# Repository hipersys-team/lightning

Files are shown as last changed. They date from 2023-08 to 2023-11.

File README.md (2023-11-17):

# Lightning: A Reconfigurable Photonic-Electronic SmartNIC for Fast and Energy-Efficient Inference




<p align="center">
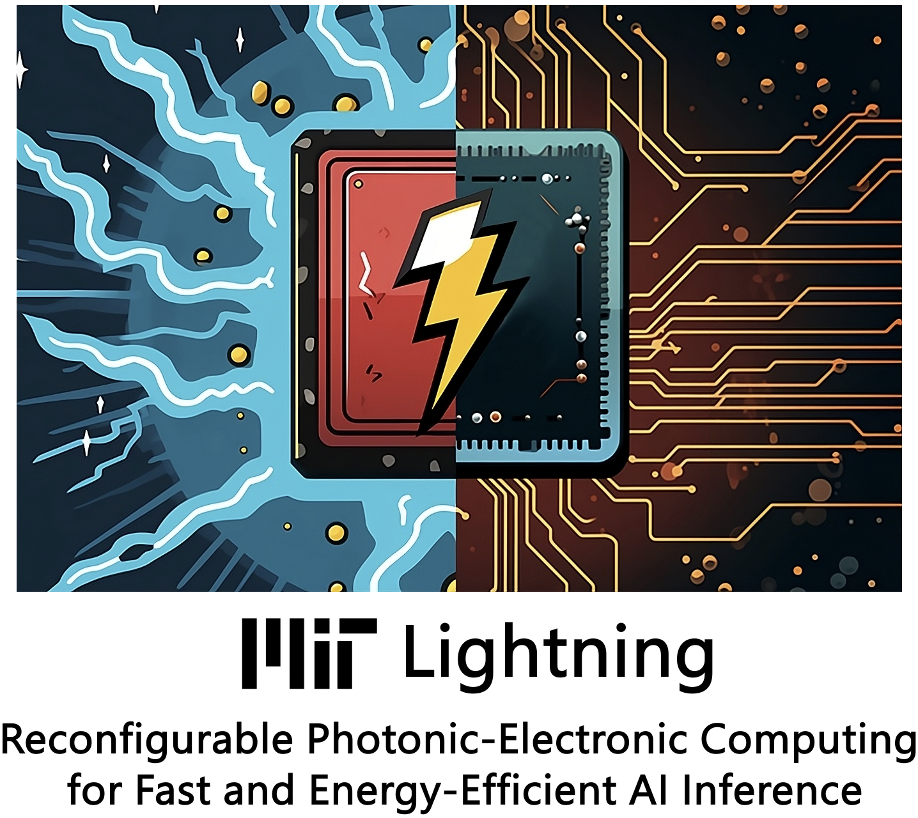
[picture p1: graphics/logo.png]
Lightning logo
 
</p>

Welcome to the Lightning, the first reconfigurable photonic-electronic neural network inference system integrated with the a 100 Gbps smartNIC.

## 1. Overview

We propose Lightning, the first reconfigurable photonic-electronic smartNIC to serve real-time deep neural network inference requests. Lightning uses a fast datapath to feed traffic from the NIC into the photonic domain without creating digital packet processing and data movement bottlenecks. To do so, Lightning leverages a novel reconfigurable count-action abstraction that keeps track of the required computation operations of each inference packet. Our count-action abstraction decouples the compute control plane from the data plane by counting the number of operations in each task and triggers the execution of the next task(s) without interrupting the dataflow. To the best of our knowledge, our prototype is the highest-frequency photonic computing system, capable of serving real-time inference queries at 4.055 GHz end-to-end.

For a full technical description on Lightning, please read our ACM SIGCOMM 2023 paper and demo:

> Z. Zhong, M. Yang, J. Lang, C. Williams, L. Kronman, A. Sludds, H. Esfahanizadeh, D. Englund, M. Ghobadi, "Lightning: A Reconfigurable Photonic-Electronic SmartNIC for Fast and Energy-Efficient Inference," ACM SIGCOMM, 2023. <https://doi.org/10.1145/3603269.3604821>

> Z. Zhong, M. Yang, J. Lang, D. Englund, M. Ghobadi, "Demo: First Demonstration of Real-Time Photonic-Electronic DNN Acceleration on SmartNICs," ACM SIGCOMM, 2023. <https://doi.org/10.1145/3603269.3610842>

For more details on Lightning, please visit our website: <https://lightning.mit.edu>

This is an active project, if you want to have a community discussion, please start a new discussion thread in the discussion tab, and we will get back to you as soon as possible.

For any questions, please contact Zhizhen Zhong at zhizhenz [at] mit.edu. We welcome all contributions and feedbacks.

## 2. Artifact Structure

This repo has submodules, please clone the repo using git recursive clone.
```
git clone --recursive 
```

### 2.1 Verilog RTL code on the Lightning datapath design and implementation

This part of artifact contains Lightning's RTL-based datapath design and implementation (Sections 4, 5, and 6 of the Lightning SIGCOMM paper). We also include an emulated photonic MAC core to build a cycle-accurate testbench using Verilator.

|  Source Files |  Description |
|  ----- |  ----- |
|  `rtl/datapath/` |  This folder contains the code of Lightning's datapath modules (packet I/O, memory controller, count-action logic, etc.) |
|  `rtl/emulate/` |  This folder contains the code of emulated photonic multiplier modules |
|  `rtl/sram/` |  This folder contains the code of SRAM modules |
|  `rtl/tb/` |  This folder contains the code of Verilator-based testbench modules |
|  `rtl/utils/` |  This folder contains the code of customized AXI-related modules and third-party AXI libraries |
|  `rtl/Makefile` |  This folder contains the Makefile for running the Verilator-based testbench |
|  `rtl/README.md` |  This README file explains the dependencies and steps to run the RTL cycle-accurate testbench |

### 2.2 FPGA firmware and library code for Lightning's Python API

This part of artifact contains the FPGA firmware and library code to enable Lightning's Python API (Section 6 and Appendix G of the Lightning SIGCOMM paper).

|  Source Files |  Description |
|  ----- |  ----- |
|  `api/firmware/` |  This folder contains the code of the FPGA firmwares to support the Python API |
|  `api/lightning_lib/` |  This folder contains the code of Lightning Python API libraries |

### 2.3 Photonic noise emulation code

This part of artifact contains Lightning's photonic emulation (Section 7 of the Lightning SIGCOMM paper).

|  Source Files |  Description |
|  ----- |  ----- |
|  `emulation/` |  This folder contains the code for running photonic emulation on large deep neural networks |
|  `emulation/README.md`  |  This file contains the dependencies and steps to run the emulation code |

### 2.4 Large-scale event-driven simulation code

This part of artifact contains Lightning's event-driven simulation study on seven real-world large DNN models (Section 9 of the Lightning SIGCOMM paper).
|  Source Files |  Description |
|  ----- |  ----- |
|  `simulation/` |  This folder contains the code for running event-driven simulations on DNN inference queries |
|  `simulation/README.md`  |  This file contains the dependencies and steps to run the simulations code |

### 2.5 Developer kit manufacture files

This part of artifact contains manufacture files for the Lightning developer kit (Appendix G of the Lightning SIGCOMM paper).

|  Source Files |  Description |
|  ----- |  ----- |
|  `kit/laser_cutting/` |  This folder contains the design files for manufactoring the package of the developer kit using laser-cutting machines |
|  `kit/3D_printing/` |  This folder contains the design files for manufactoring the device support components using 3D printers |
|  `kit/lightning_devkit_v2.jpg`|  This file contains the shopping list to assembly the open-source developer kit |

### 2.6 Data files

This part of artifact contains the data to reproduce our results.

|  Source Files |  Description |
|  ----- |  ----- |
|  `data/saved_dataset/` |  This folder stores the datasets for corresponding DNN models |
|  `data/saved_models/` |  This folder stores the considered DNN models |

### 2.7 Automatic DNN accuracy checker

This part of artifact contains automatic github actions like the DNN accuracy checker through our Verilator-based testbench.

|  Source Files |  Description |
|  ----- |  ----- |
|  `.github/workflows/` |  This folder stores the automatic workflows like DNN accuracy checker |

## 3. Major Dependencies

* Xilinx Vivado 2022.2
* Xilinx PetaLinux 2022.2
* Ubuntu 20.04.6 LTS (Focal Fossa)
* Verilator 4.038 2020-07-11 rev v4.036-114-g0cd4a57ad
* Python 3.10.8
* Detailed dependencies is described in the README.md of each folder

## 4. License

Lightning is MIT-licensed.

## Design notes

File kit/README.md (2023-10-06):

# Building your own Lightning Developer Kit

The Lightning developer kit contains the minimum-viable photonic devices to perform a single multiplication operation in the photonic domain. The current version of Lightning developer kit takes in two input signals (in analog voltages, represented by $A$ and $B$), and returns an output signal  (in analog voltages, represented by $R$). For each operation, $R=A*B$ is performed in photonic domain inside the Lightning developer kit. For more details, please refer to the Appendix of our [paper](https://doi.org/10.1145/3603269.3604821).

<p align="center">
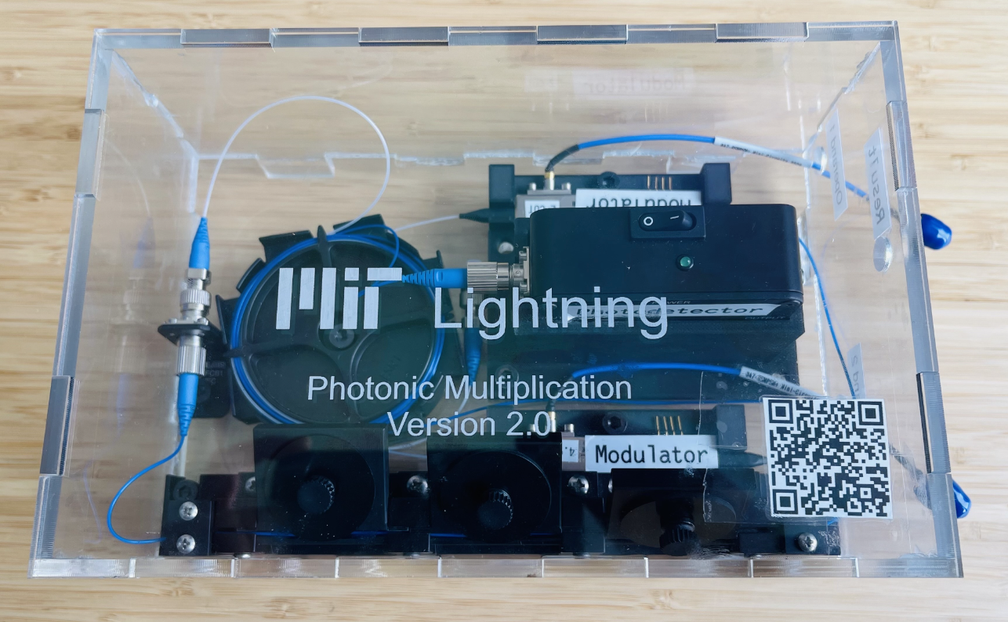
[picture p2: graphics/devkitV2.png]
kit
 
</p>

## Shopping list

To build your own Lightning developer kit as shown in the figure, you need to purchase the following devices:
- Modulator: [Thorlabs 10 GHz Intensity Modulator](https://www.thorlabs.com/thorproduct.cfm?partnumber=LN81S-FC)
- Photodetector: [Thorlabs DC - 9.5 GHz InGaAs Detector](https://www.thorlabs.com/thorproduct.cfm?partnumber=PDA8GS)
- Fiber polarization controller: [Thorlabs 3 Ø27 mm Paddles](https://www.thorlabs.com/thorproduct.cfm?partnumber=FPC031)
- Acrylic sheets: [Clear Static-Dissipative Cast Acrylic, Scratch and UV Resistant, 12" x 24" x 3/16"](https://www.mcmaster.com/sheets/clear-static-dissipative-scratch-and-uv-resistant-cast-acrylic/)
- Fiber storage reels:[Thorlabs Storage Reel for Patch Cables with Ø900 µm Jackets](https://www.thorlabs.com/thorproduct.cfm?partnumber=FSR1)
- Fiber mating sleeves: [Thorlabs Single L-Bracket Mating Sleeve](https://www.thorlabs.com/thorproduct.cfm?partnumber=ADAFCPMB1), [Thorlabs Dual L-Bracket Mating Sleeve](https://www.thorlabs.com/thorproduct.cfm?partnumber=ADAFCPMB3)

## Fabrications
The Lightning developer kit's case is made by transparent acrylic sheets cutted by laser cutting machines. You can find the laser cutting source files in ```laser_cutting/```.

To secure the position of photonic devices inside the Lightning developer kit, we designed customized device support and fabricated them using 3D printers. You can find the 3D printing source files in ```3D_printing/```.

## Supporting equipment
To facilitates the Lightning developer kit and use it to test out your ideas on photonic computing, you will need the following equipment to build a minimum-viable testbed. Note that these equipment are not mandatory and can be replaced if you find other alternatives. 

- Laser source: [Santec TSL-770 Tunable Laser](https://inst.santec.com/products/tunablelaser/tsl-770)
- DAC/ADC (on RFSoC FPGA): [AMD Xilinx ZCU111](https://www.xilinx.com/products/boards-and-kits/zcu111.html)
- RF amplifier: [Texas Instruments LMH5401 Evaluation Module
](https://www.ti.com/tool/LMH5401EVM)

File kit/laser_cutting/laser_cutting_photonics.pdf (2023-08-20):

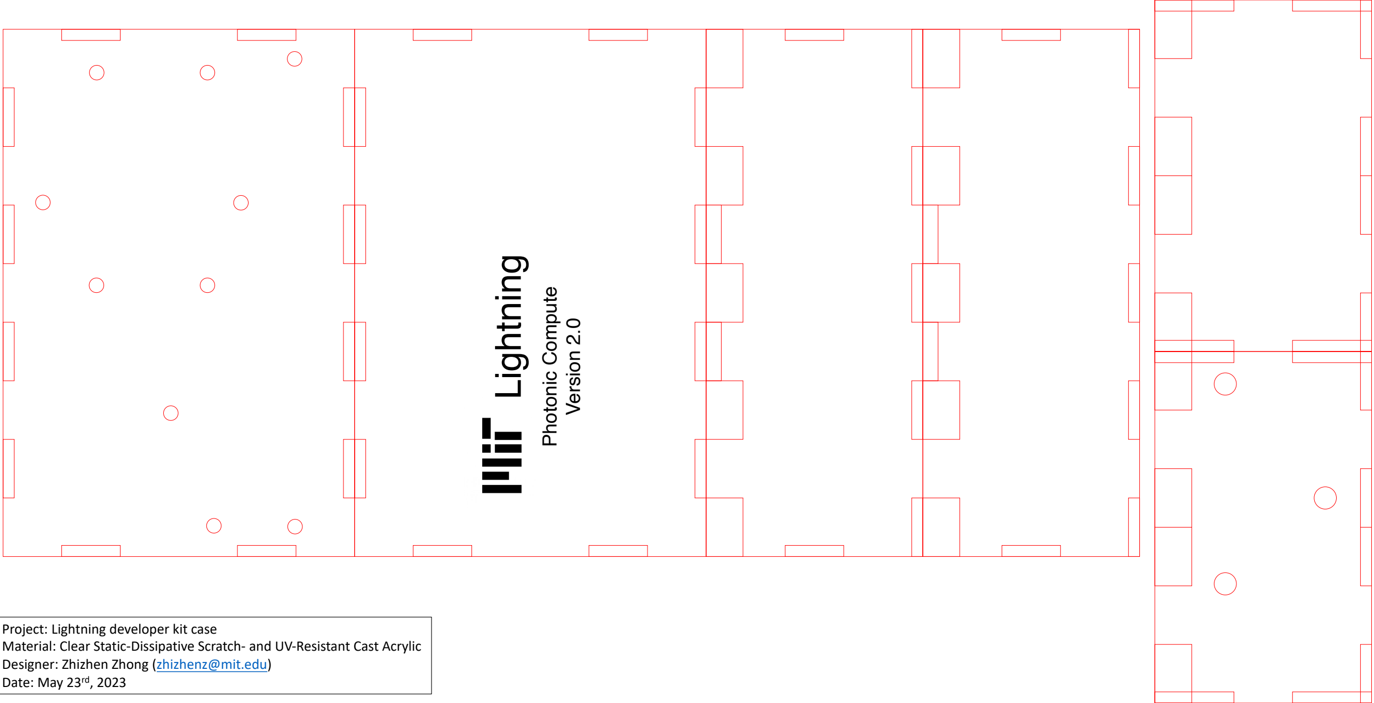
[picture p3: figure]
Lightning; Photonic Compute; Version 2.0; Project: Lightning developer kit case; Designer: Zhizhen Zhong (zhizhenz@mit.edu) Date: May 23rd, 2023

Material: Clear Static-Dissipative Scratch- and UV-Resistant Cast Acrylic

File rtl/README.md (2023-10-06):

# Lightning Register Transfer Level (RTL) Code
The Lightning RTL code implements the novel "reconfigurable count-action" based datapath that handles the data movement from ML inference request packets to the final result packets. In particular, our reconfigurable count-action abstraction decouples the control and data planes of inference requests by enabling the datapath to keep track of the directed acyclic graph (DAG) of each inference request for DNN models without interrupting the flow of the data in and out of photonic computing cores.

The code in this folder reproduces results reported in Lightning paper Section 6.

## Reproduce the testbench results

### 1. Install [Verilator](https://verilator.org/guide/latest/install.html) and dependencies
Run ```python tb/create_venv.py``` to create the environments and dependencies<br>
Run ```sudo apt install -y verilator python3 python3-pip python3-venv``` to install verilator<br>
Run ```verilator --version``` to check if the install version is ```Verilator 4.038 2020-07-11 rev v4.036-114-g0cd4a57ad```. Other Verilator versions may or may not be compatible due to frequent Verilator codebase changes.

### 2. Build the Verilator testbench
Run ```make build-sw-lenet-single-core``` <br>
If build is successful, the compiled Verilator testbench will appear in the ```obj_dir/``` folder.

### 3. Run the Verilator testbench (e.g., LeNet-300-100 DNN)
Run ```make run-sw-lenet-single-core``` <br>
After running the testbench, results will appear in the ```tb/``` folder:
- ```tb_lenet_sim.vcd```: the generated waveform file containing all registers values over the simulation period.
- ```tb_lenet_sim_reg_values```: the register values at each cycle in .csv format recorded by the Verilator [Direct Programming Interface (DPI)
](https://verilator.org/guide/latest/connecting.html#direct-programming-interface-dpi).

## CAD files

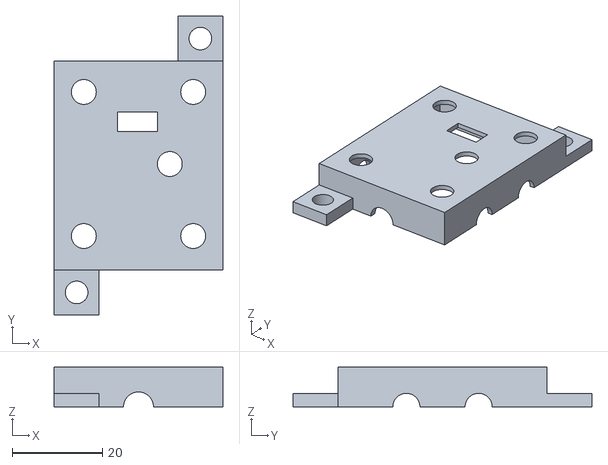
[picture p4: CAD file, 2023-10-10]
kit/3D_printing/amp_support_top.STL
37.4 x 66.2 x 8.80

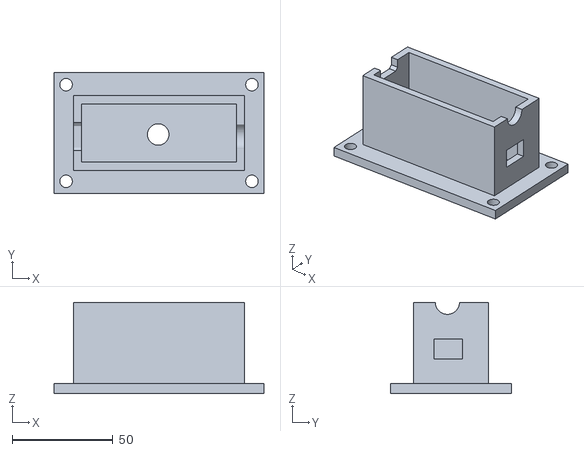
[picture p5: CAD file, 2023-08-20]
kit/3D_printing/pd_support.STL
104.2 x 59.9 x 45.4

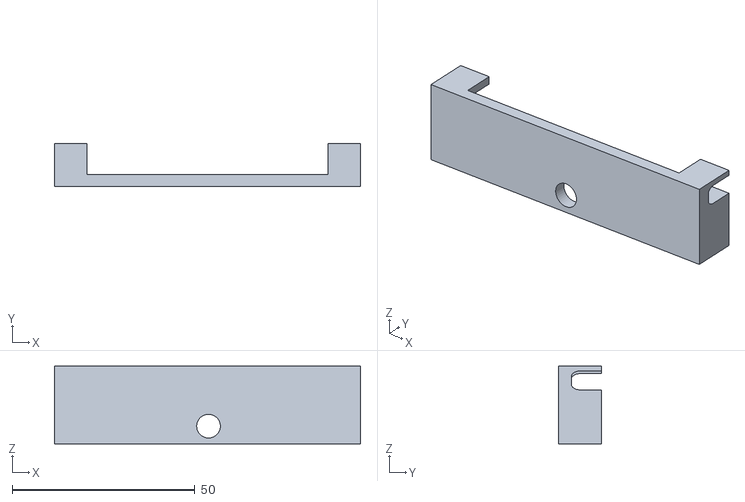
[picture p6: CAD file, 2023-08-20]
kit/3D_printing/modulator_support.STL
83.8 x 11.9 x 21.3

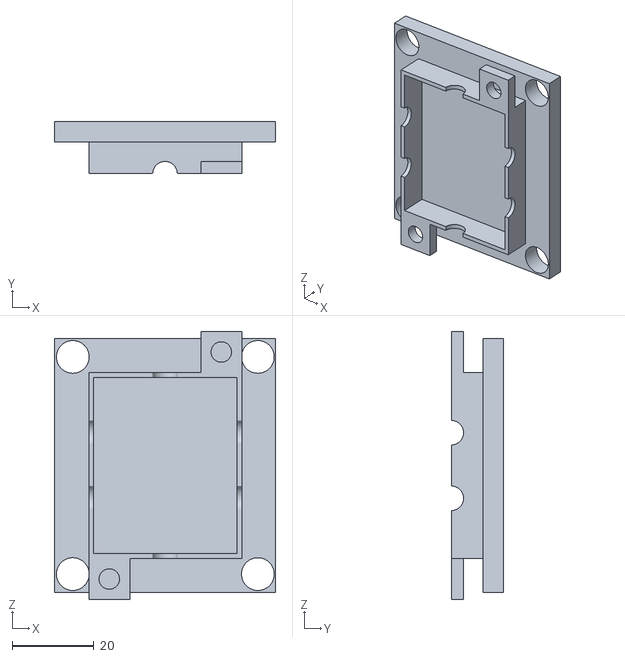
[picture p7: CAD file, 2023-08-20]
kit/3D_printing/amp_support.STL
54.0 x 12.8 x 65.4

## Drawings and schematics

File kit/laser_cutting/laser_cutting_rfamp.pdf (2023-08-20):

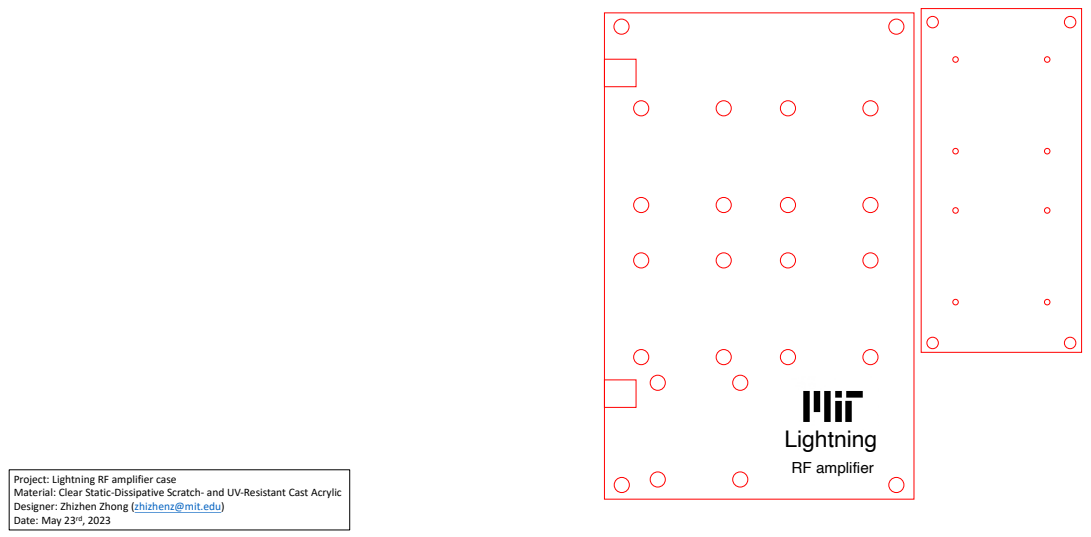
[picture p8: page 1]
Lightning; - and UV )

RF amplifier Project: Lightning RF amplifier case
Material: Clear Static
Designer: Zhizhen Zhong
Date: May 23rd

-Dissipative Scratch
(zhizhenz@mit.edu

-Resistant Cast Acrylic

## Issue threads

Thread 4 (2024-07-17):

How to build the zcu111 vivado project？

canchen0720, 2024-07-17:
Hi，
    I want learn the lightning project. But I can't work out how to build the vivado project.
    In the 'rtl' folder, we can do the simulation via 'tb' and can see the waveform of the code.
    And in the 'platform' folder, we can build the petalinux project. But the petalinux prj needs the '.xsa' file which can be generated by the vivado.
   So which folder related the progress of building ZCU111 vivado prj？Or it's not open source and I have to build the project myself？

Thanks

Closed 2024-07-18.

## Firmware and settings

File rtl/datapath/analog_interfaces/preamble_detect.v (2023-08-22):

/*

Project: [Lightning] A Reconfigurable Photonic-Electronic SmartNIC for Fast and Energy-Efficient Inference 
File: preamble_detect.v
File Explanation: this module describes the preamble detection logic to distinguish meaningful data from continuous coming out of ADC
File Start Time: December 2022
Authors: Zhizhen Zhong (zhizhenz@mit.edu)
Language: Verilog 2001

*/

`resetall
`timescale 1ns / 1ps
`default_nettype none


module preamble_detect # (
    parameter CYCLE_SAMPLE_NUM = 16,
    parameter DATA_WIDTH = 256
)(
    input wire clk,
    input wire rst,
    input wire state_changed,
    input wire [DATA_WIDTH-1:0] input_adc_tdata,
    input wire input_adc_tvalid,
    input wire [15:0] monitor_cycle_length,
    input wire [15:0] preamble_cycle_length,

    output reg [255:0] pattern_match_agg,
    output reg [15:0]  matched_pattern,
    output reg [DATA_WIDTH-1:0] output_detected_tdata,
    output reg output_detected_tvalid
);
    reg [15:0] pattern_match [15:0];
    reg [15:0] pattern_match_error;

    wire [CYCLE_SAMPLE_NUM-1:0] average_tdata;
    wire average_tvalid;

    wire [DATA_WIDTH-1:0] delay_tdata;
    wire delay_tvalid;
    reg [DATA_WIDTH-1:0] buffer_tdata;
    reg buffer_tvalid;

    reg [DATA_WIDTH-1:0] post_tail_tdata;
    reg post_tail_tvalid;

    reg [15:0] compare_with_average;

    integer x;
    always @ (posedge clk)
        if (rst) begin
            output_detected_tdata <= {DATA_WIDTH{1'b0}};
            output_detected_tvalid <= 1'b0;
            for (x=0; x<16; x=x+1) begin
                pattern_match[x] <= 0;
            end
            pattern_match_error <= 0;
            compare_with_average <= 16'd0;
            pattern_match_agg <= 0;
            
        end else if (state_changed) begin
            output_detected_tdata <= {DATA_WIDTH{1'b0}};
            output_detected_tvalid <= 1'b0;
            for (x=0; x<16; x=x+1) begin
                pattern_match[x] <= 0;
            end
            pattern_match_error <= 0;
            compare_with_average <= 16'd0;
            pattern_match_agg <= 0;

        end else begin
            for (x=0; x<16; x=x+1) begin
                pattern_match_agg[x*16 +: 16] <= pattern_match[x];
            end

            if (average_tvalid) begin
                for (x=0; x<16; x=x+1) begin
                    if (delay_tdata[x*16 +: 16] < average_tdata) begin
                        compare_with_average[x] <= 1'b0;
                    end else begin
                        compare_with_average[x] <= 1'b1;
                    end
                end

                if (compare_with_average == 16'b0000_0000_1111_1111) begin
                    pattern_match[0] <= pattern_match[0] + 1;
                end else if (compare_with_average == 16'b0000_0001_1111_1110) begin
                    pattern_match[1] <= pattern_match[1] + 1;
                end else if (compare_with_average == 16'b0000_0011_1111_1100) begin
                    pattern_match[2] <= pattern_match[2] + 1;
                end else if (compare_with_average == 16'b0000_0111_1111_1000) begin
                    pattern_match[3] <= pattern_match[3] + 1;
                end else if (compare_with_average == 16'b0000_1111_1111_0000) begin
                    pattern_match[4] <= pattern_match[4] + 1;
                end else if (compare_with_average == 16'b0001_1111_1110_0000) begin
                    pattern_match[5] <= pattern_match[5] + 1;
                end else if (compare_with_average == 16'b0011_1111_1100_0000) begin
                    pattern_match[6] <= pattern_match[6] + 1;
                end else if (compare_with_average == 16'b0111_1111_1000_0000) begin
                    pattern_match[7] <= pattern_match[7] + 1;
                end else if (compare_with_average == 16'b1111_1111_0000_0000) begin
                    pattern_match[8] <= pattern_match[8] + 1;
                end else if (compare_with_average == 16'b1111_1110_0000_0001) begin
                    pattern_match[9] <= pattern_match[9] + 1;
                end else if (compare_with_average == 16'b1111_1100_0000_0011) begin
                    pattern_match[10] <= pattern_match[10] + 1;
                end else if (compare_with_average == 16'b1111_1000_0000_0111) begin
                    pattern_match[11] <= pattern_match[11] + 1;
                end else if (compare_with_average == 16'b1111_0000_0000_1111) begin
                    pattern_match[12] <= pattern_match[12] + 1;
                end else if (compare_with_average == 16'b1110_0000_0001_1111) begin
                    pattern_match[13] <= pattern_match[13] + 1;
                end else if (compare_with_average == 16'b1100_0000_0011_1111) begin
                    pattern_match[14] <= pattern_match[14] + 1;
                end else if (compare_with_average == 16'b1000_0000_0111_1111) begin
                    pattern_match[15] <= pattern_match[15] + 1;
                end else begin
                    pattern_match_error <= pattern_match_error + 1;
                end
            end 

            // this is exact match
            if (pattern_match[0] >= preamble_cycle_length && preamble_cycle_length > 0) begin
                output_detected_tdata <= post_tail_tdata;
                output_detected_tvalid <= post_tail_tvalid;
                matched_pattern <= 16'b0000_0000_1111_1111;
            // these are shifted match
            end else if (pattern_match[1] >= preamble_cycle_length-1 && preamble_cycle_length > 0) begin
                output_detected_tdata <= {delay_tdata[15:0], post_tail_tdata[255:16]};
                output_detected_tvalid <= post_tail_tvalid;
                matched_pattern <= 16'b0000_0001_1111_1110;

            end else if (pattern_match[2] >= preamble_cycle_length-1 && preamble_cycle_length > 0) begin
                output_detected_tdata <= {delay_tdata[31:0], post_tail_tdata[255:32]};
                output_detected_tvalid <= post_tail_tvalid;
                matched_pattern <= 16'b0000_0011_1111_1100;

            end else if (pattern_match[3] >= preamble_cycle_length-1 && preamble_cycle_length > 0) begin
                output_detected_tdata <= {delay_tdata[47:0], post_tail_tdata[255:48]};
                output_detected_tvalid <= post_tail_tvalid;
                matched_pattern <= 16'b0000_0111_1111_1000;

            end else if (pattern_match[4] >= preamble_cycle_length-1 && preamble_cycle_length > 0) begin
                output_detected_tdata <= {delay_tdata[63:0], post_tail_tdata[255:64]};
                output_detected_tvalid <= post_tail_tvalid;
                matched_pattern <= 16'b0000_1111_1111_0000;

            end else if (pattern_match[5] >= preamble_cycle_length-1 && preamble_cycle_length > 0) begin
                output_detected_tdata <= {delay_tdata[79:0], post_tail_tdata[255:80]};
                output_detected_tvalid <= post_tail_tvalid;
                matched_pattern <= 16'b0001_1111_1110_0000;
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

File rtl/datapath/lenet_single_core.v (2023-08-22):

/*

Project: [Lightning] A Reconfigurable Photonic-Electronic SmartNIC for Fast and Energy-Efficient Inference 
File: lenet_single_core.v
File Explanation: this module describes the top-level logic for executing fully-connected LeNet-300-100 neural networks
File Start Time: Februry 2022
Authors: Zhizhen Zhong (zhizhenz@mit.edu)
Language: Verilog 2001

*/


`resetall
`timescale 1ns / 1ps
`default_nettype none


module lenet_single_core # (
    parameter ADC_BITWIDTH = 256,
    parameter DAC_BITWIDTH = 256,
    parameter INFERENCE_INPUT_NUM = 784,
    parameter INFERENCE_INPUT_CYCLE = 49,
    parameter LAYER_1_OUTPUT_NUM = 300,
    parameter LAYER_1_OUTPUT_CYCLE = 19,
    parameter LAYER_1_ALL_CYCLE = 14700,
    parameter LAYER_2_OUTPUT_NUM = 100,
    parameter LAYER_2_OUTPUT_CYCLE = 7,
    parameter LAYER_2_ALL_CYCLE = 1900,
    parameter LAYER_3_OUTPUT_NUM = 10,
    parameter LAYER_3_OUTPUT_CYCLE = 1,
    parameter LAYER_3_ALL_CYCLE = 70
) (
    input wire                       clk,
    input wire                       rst,

    // initial input data from model runner, sourced from SRAM or CMAC
    input wire [DAC_BITWIDTH-1:0]    initial_input_axis_tdata,
    input wire                       initial_input_axis_tvalid,
    input wire                       initial_input_axis_tlast,
    output wire                      initial_input_axis_tready,

    // DNN weights data from model runner, sourced from SRAM or DRAM
    input wire [DAC_BITWIDTH-1:0]    weight_matrix_tdata,
    input wire                       weight_matrix_tvalid,
    output wire                      weight_matrix_tready,
    input wire [ADC_BITWIDTH/16-1:0] weight_sign_tdata,
    input wire                       weight_sign_tvalid,
    output wire                      weight_sign_tready,

    // received data from ADC channels
    input  wire [ADC_BITWIDTH-1:0]   adc_00_axis_tdata,  // photonic multiplication input
    input  wire                      adc_00_axis_tvalid,
    output wire                      adc_00_axis_tready,

    // send data to DAC channels
    output wire [DAC_BITWIDTH-1:0]   dac_00_axis_tdata,  // DNN input image data
    output wire                      dac_00_axis_tvalid,
    input  wire                      dac_00_axis_tready,

    output wire [DAC_BITWIDTH-1:0]   dac_01_axis_tdata,  // DNN weight data
    output wire                      dac_01_axis_tvalid,
    input  wire                      dac_01_axis_tready,

    // input control signals
    input  wire                      inference_start,  // start the inference
    input  wire                      calibration_start,  // start the calibration
    input  wire                      weight_ready,
    input  wire                      use_sparsity,
    input  wire [15:0]               input_image_index,
    input  wire [15:0]               optical_loss,
    input  wire [15:0]               monitor_cycle_length,
    input  wire [15:0]               preamble_cycle_length,
    input  wire [15:0]               calibration_length_wire,
    input  wire [15:0]               calibration_wave_type,
    input  wire [15:0]               estimate_photonic_slack_cycle_length,
    input  wire [15:0]               propagation_cycle_delay_between_modulators,
    input  wire [15:0]               propagation_cycle_shift_between_modulators,  // each cycle only has 16 numbers

    // output results
    output wire                      state_changed_wire,
    output wire                      reset_all_wire,
    output wire                      photonic_integration_start_wire,
    output reg [DAC_BITWIDTH-1:0]    final_result_tdata,
    output reg                       final_result_tvalid,
    output reg [15:0]                in_module_layer,
    output wire [255:0]              pattern_match_agg,
    output wire [15:0]               calibrated_loss,
    output wire                      calibrated_loss_valid,
    output reg [15:0]                start_clock_count,
    output reg [15:0]                final_clock_count
);

    reg                         state_changed;
    reg                         reset_all;
    reg                         photonic_integration_start;
    assign state_changed_wire = state_changed;
    assign reset_all_wire     = reset_all;
    assign photonic_integration_start_wire = photonic_integration_start;
    reg                     reset_all_state;

    reg [DAC_BITWIDTH-1:0]  calibration_input_tdata;
    reg                     calibration_input_tvalid;
    wire [DAC_BITWIDTH-1:0] calibration_output_tdata;
    wire                    calibration_output_tvalid;

    wire [DAC_BITWIDTH-1:0] layer_activation_tdata;
    wire                    layer_activation_tvalid;
    wire                    layer_activation_tlast;

    reg                     dac_0x_axis_tvalid;
    assign                  adc_00_axis_tready = 1'b1;

    reg  [DAC_BITWIDTH-1:0] dac_00_delay_tdata;
    reg                     dac_00_delay_tvalid;
    reg  [DAC_BITWIDTH-1:0] dac_01_delay_tdata;
    reg                     dac_01_delay_tvalid;

    wire [ADC_BITWIDTH-1:0] adc_00_accept_tdata;
    wire                    adc_00_accept_tvalid;

    wire [DAC_BITWIDTH/16-1:0] sparsity_tdata;
    wire                       sparsity_tvalid;
    wire [DAC_BITWIDTH/16-1:0] detected_sparsity_tdata;
    wire                       detected_sparsity_tvalid;

    wire                    photonic_multiplication_tvalid = adc_00_accept_tvalid;
    reg                     photonic_multiplication_tvalid_state;

    wire [ADC_BITWIDTH-1:0] amplified_adc_00_axis_tdata;
    wire                    amplified_adc_00_axis_tvalid;

    wire [ADC_BITWIDTH/16-1:0] integration_photonic_output_tdata;
    wire                    integration_photonic_output_tvalid;
    wire                    integration_photonic_output_tready;

    wire [ADC_BITWIDTH/16-1:0] nonlinear_photonic_output_tdata;
    wire                    nonlinear_photonic_output_tvalid;
    wire                    nonlinear_photonic_output_tready;

    wire [DAC_BITWIDTH-1:0] new_input_activation_tdata;
    wire                    new_input_activation_tvalid;
    wire                    new_input_activation_tlast;

    wire [DAC_BITWIDTH-1:0] final_softmax_tdata;
    wire                    final_softmax_tvalid;

    // handling control counters
    wire [15:0] new_layer = in_module_layer;  // layer information
    reg [15:0]              new_input;  // input image index
    reg [15:0]              current_layer;
    reg [15:0]              current_input;
    wire [2:0]              output_layer_info;

    /* performance metrics */
    `define COUNTER_PHOTONICS   0
    `define COUNTER_INTEGRATION 1
    `define COUNTER_RELU        2
    `define COUNTER_SOFTMAX     3

    `define SIGNAL_INPUT        0
    `define SIGNAL_OUTPUT       1

    reg [15:0]              latency_counter, compute_counter;
    reg [3:0]               module_countme;
    reg [1:0]               module_signals [3:0];
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

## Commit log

2023-08-20 add dev kit design files and verilog AXI submodules
    [amp_support.STL, modulator_support.STL, pd_support.STL]
2023-10-10 release amplifier support case's top STL
    [amp_support_top.STL]
